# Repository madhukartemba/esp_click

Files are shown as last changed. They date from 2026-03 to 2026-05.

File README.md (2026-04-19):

# esp_click
This is a deep sleep ESP32 C6 push button device which transmits clicks via ESPNOW protocol. It uses an ESP32C6 microcontroller.

## Firmware build: broken RISC-V toolchain (PlatformIO)

ESP32-C6 uses the RISC-V toolchain (`riscv32-esp-elf-g++`). If the build fails with:

`sh: riscv32-esp-elf-g++: command not found` (exit 127)

the compiler package is missing, incomplete, or PlatformIO’s environment did not pick it up. From the firmware directory (`esp_click_firmware`), remove the toolchain and project build cache, then rebuild so PlatformIO re-downloads the toolchain:

```bash
cd esp_click_firmware
rm -rf .pio
rm -rf ~/.platformio/packages/toolchain-riscv32-esp
rm -rf ~/.platformio/tools/toolchain-riscv32-esp
pio run
```

Optional: remove all installed compiler packages (they reinstall on demand):

```bash
rm -rf ~/.platformio/packages/toolchain-*
```

Optional: prune unused PlatformIO packages:

```bash
pio system prune
```

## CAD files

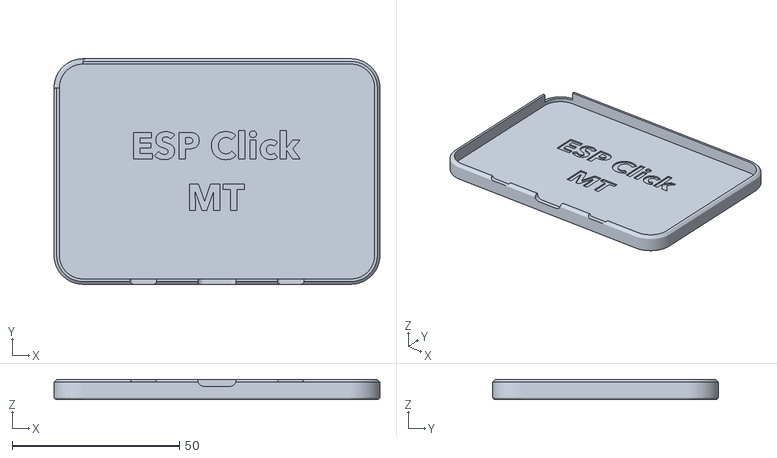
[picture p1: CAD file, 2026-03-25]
3D Print/Wall Mount 2.stl
97.4 x 67.4 x 6.00

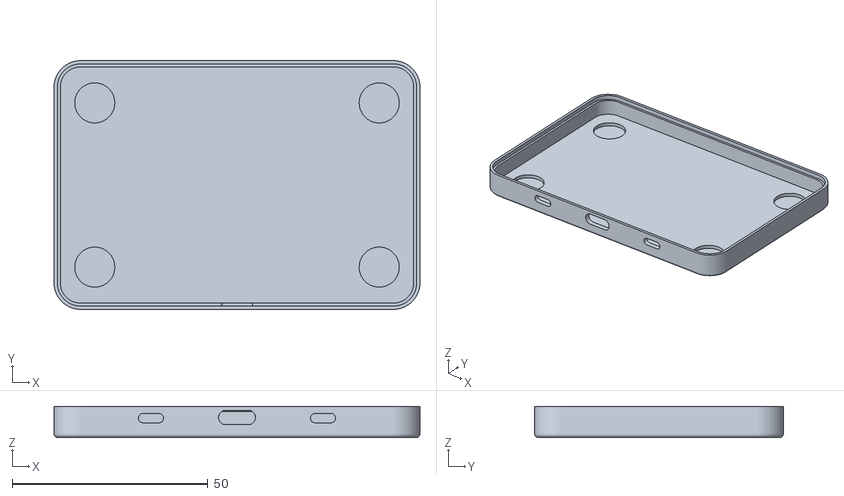
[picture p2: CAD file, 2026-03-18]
3D Print/Bottom.stl
93.6 x 63.6 x 8.00

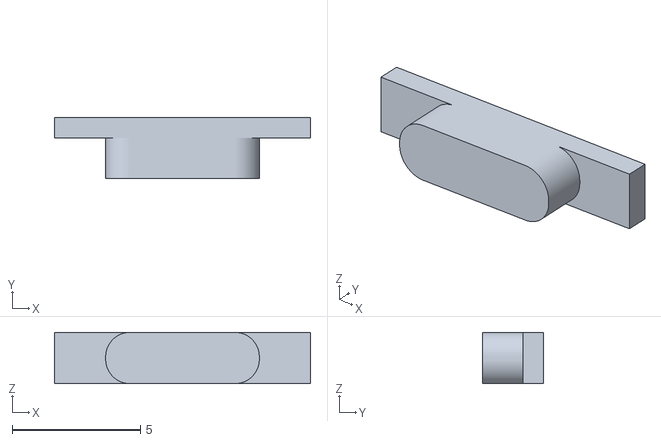
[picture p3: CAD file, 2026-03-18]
3D Print/CaseButton1.stl
10.0 x 2.40 x 2.00

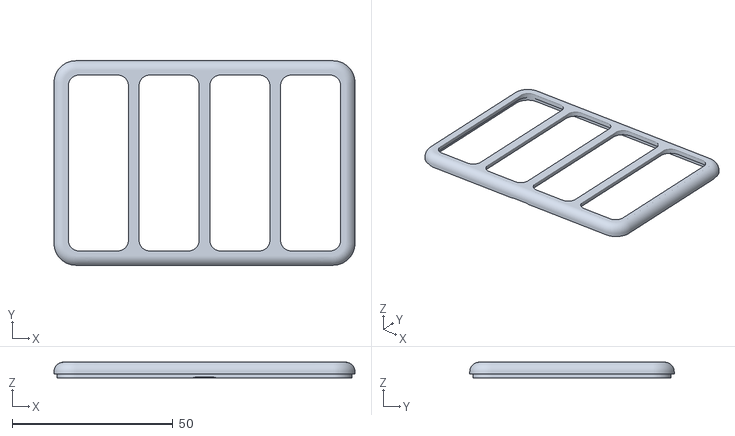
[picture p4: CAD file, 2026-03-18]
3D Print/Top.stl
93.6 x 63.6 x 4.90

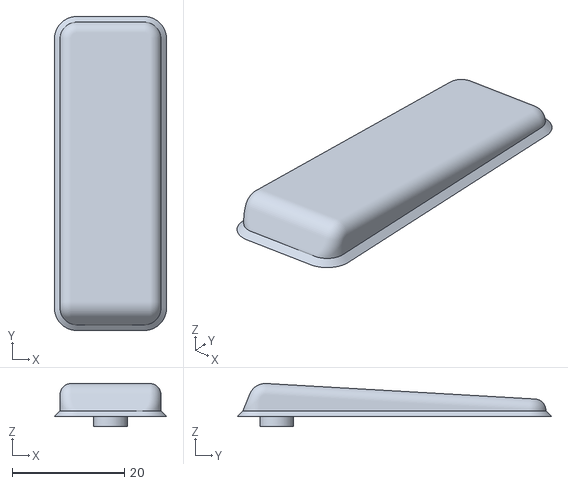
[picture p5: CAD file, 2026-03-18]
3D Print/Switch.stl
20.0 x 56.0 x 7.68

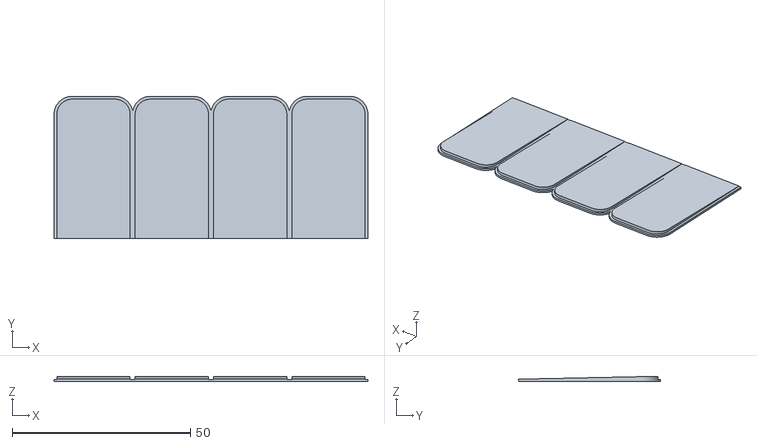
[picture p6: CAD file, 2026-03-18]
3D Print/SocketMount.stl
88.2 x 40.0 x 1.50

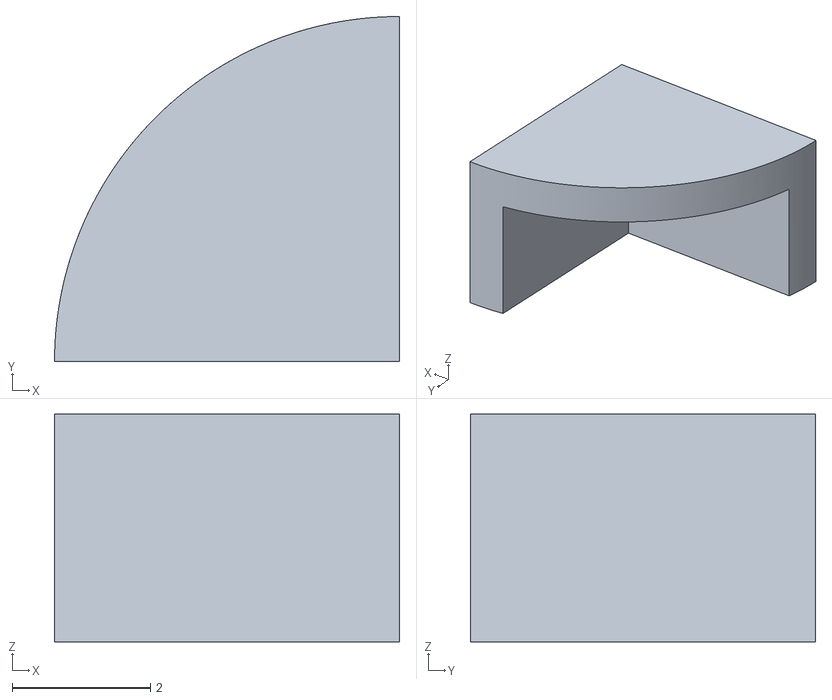
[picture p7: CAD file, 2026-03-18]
3D Print/LedGuide.stl
5.00 x 5.00 x 3.30

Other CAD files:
3D Print/ESPClick.f3z

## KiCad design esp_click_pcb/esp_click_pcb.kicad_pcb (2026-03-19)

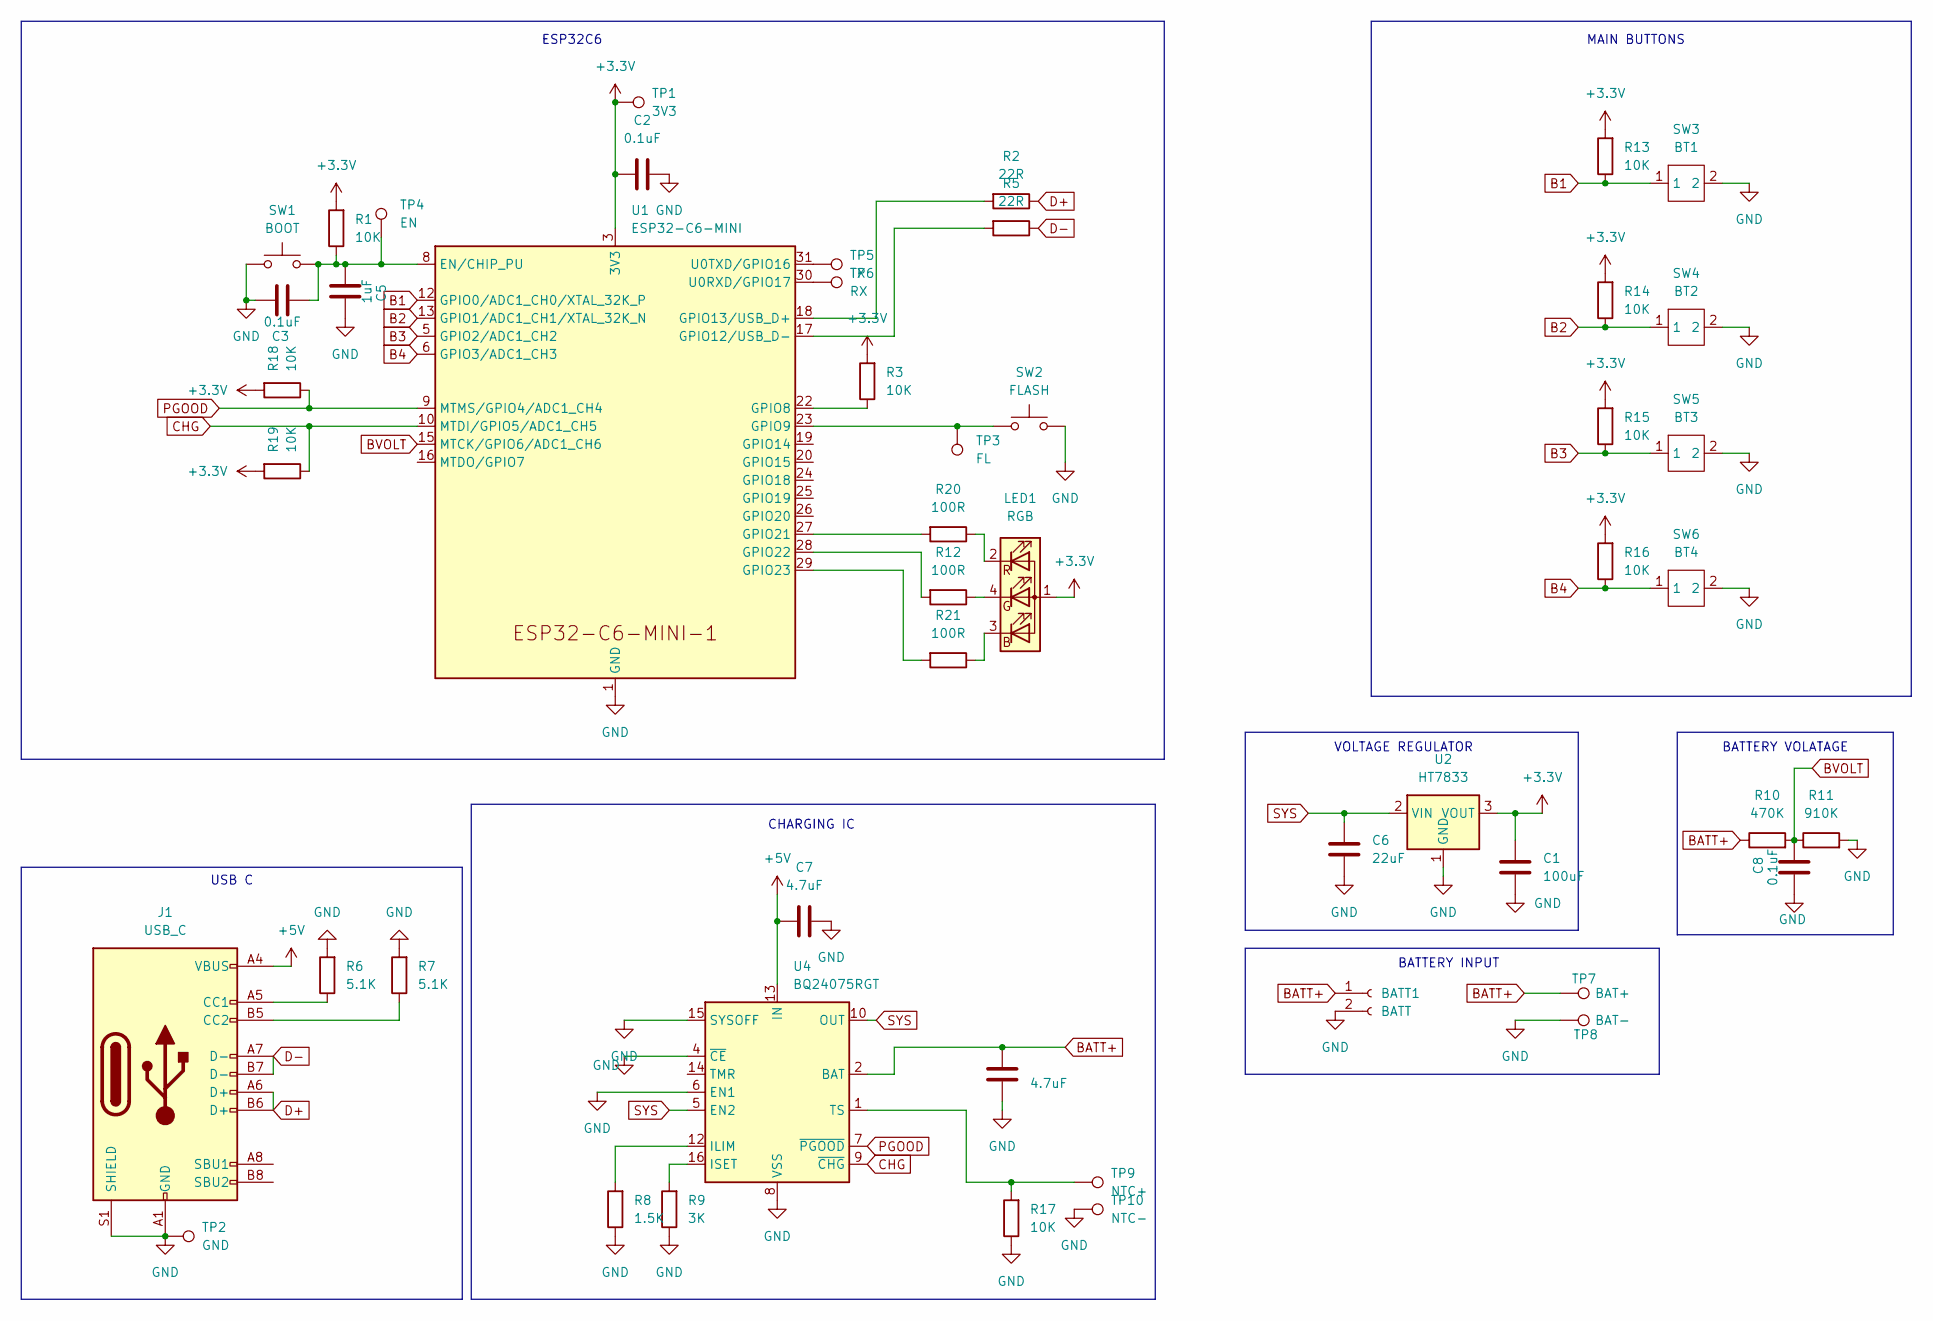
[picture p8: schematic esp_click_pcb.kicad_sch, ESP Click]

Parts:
BATT1: BATT; JST_SHL_SM02B-SHLS-TF_1x02-1MP_P1.00mm_Horizontal
C1: 100uF; C_0805_2012Metric
C2, C3, C8: 0.1uF; C_0603_1608Metric
C4, C7: 4.7uF; C_0805_2012Metric
C5: 1uF; C_0603_1608Metric
C6: 22uF; C_0805_2012Metric
J1: USB_C; USB_C_Receptacle_GCT_USB4110
LED1: RGB; XL-1615RGBC-RF
R1, R3, R13, R14, R15, R16, R17, R18, R19: 10K; R_0603_1608Metric
R2, R5: 22R; R_0603_1608Metric
R6, R7: 5.1K; R_0603_1608Metric
R8: 1.5K; R_0603_1608Metric
R9: 3K; R_0603_1608Metric
R10: 470K; R_0603_1608Metric
R11: 910K; R_0603_1608Metric
R12, R20, R21: 100R; R_0603_1608Metric
SW1: BOOT; TST-A002_0.6MM_BOSS
SW2: FLASH; TST-A002_0.6MM_BOSS
SW3: BT1; TS6643WS
SW4: BT2; TS6643WS
SW5: BT3; TS6643WS
SW6: BT4; TS6643WS
TP1: 3V3; TestPoint_Pad_D1.5mm
TP2: GND; TestPoint_Pad_D1.5mm
TP3: FL; TestPoint_Pad_D1.5mm
TP4: EN; TestPoint_Pad_D1.5mm
TP5: TX; TestPoint_Pad_D1.5mm
TP6: RX; TestPoint_Pad_D1.5mm
TP7: BAT+; TestPoint_Pad_D2.0mm
TP8: BAT-; TestPoint_Pad_D2.0mm
TP9: NTC+; TestPoint_Pad_D1.5mm
TP10: NTC-; TestPoint_Pad_D1.5mm
U1: ESP32-C6-MINI; ESP32-C6-MINI-1
U2: HT7833; SOT-89-3
U4: BQ24075RGT; VQFN-16-1EP_3x3mm_P0.5mm_EP1.6x1.6mm

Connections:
+3.3V: C1.1, C2.1, LED1.1 (A), R1.2, R3.2, R13.2, R14.2, R15.2, R16.2, R18.2, R19.2, TP1.1, U1.3 (3V3), U2.3 (VOUT)
+5V: C7.1, J1.A4 (VBUS), J1.A9 (VBUS), J1.B4 (VBUS), J1.B9 (VBUS), U4.13 (IN)
B1: R13.1, SW3.1, U1.12 (GPIO0/ADC1_CH0/XTAL_32K_P)
B2: R14.1, SW4.1, U1.13 (GPIO1/ADC1_CH1/XTAL_32K_N)
B3: R15.1, SW5.1, U1.5 (GPIO2/ADC1_CH2)
B4: R16.1, SW6.1, U1.6 (GPIO3/ADC1_CH3)
BATT+: BATT1.1, C4.1, R10.1, TP7.1, U4.2 (BAT), U4.3 (BAT)
BVOLT: C8.2, R10.2, R11.1, U1.15 (MTCK/GPIO6/ADC1_CH6)
CHG: R19.1, U1.10 (MTDI/GPIO5/ADC1_CH5), U4.9 (~CHG)
D+: J1.A6 (D+), J1.B6 (D+), R2.1
D-: J1.A7 (D-), J1.B7 (D-), R5.1
GND: BATT1.2, C1.2, C2.2, C3.2, C4.2, C5.2, C6.2, C7.2, C8.1, J1.A1 (GND), J1.A12 (GND), J1.B1 (GND), J1.B12 (GND), J1.S1 (SHIELD), R6.2, R7.2, R8.1, R9.1, R11.2, R17.1, SW1.1, SW2.2, SW3.2, SW4.2, SW5.2, SW6.2, TP2.1, TP8.1, TP10.1, U1.1 (GND), U1.2 (GND), U1.11 (GND), U1.14 (GND), U1.36 (GND), U1.37 (GND), U1.38 (GND), U1.39 (GND), U1.40 (GND), U1.41 (GND), U1.42 (GND), U1.43 (GND), U1.44 (GND), U1.45 (GND), U1.46 (GND), U1.47 (GND), U1.48 (GND), U1.49 (GND), U1.50 (GND), U1.51 (GND), U1.52 (GND), U1.53 (GND), U2.1 (GND), U4.4 (~CE), U4.6 (EN1), U4.8 (VSS), U4.15 (SYSOFF), U4.17 (VSS)
unnamed: J1.A5 (CC1), R6.1
unnamed: J1.B5 (CC2), R7.1
unnamed: LED1.3 (BK), R21.1
unnamed: LED1.4 (GK), R12.1
unnamed: LED1.2 (RK), R20.1
unnamed: C3.1, C5.1, R1.1, SW1.2, TP4.1, U1.8 (EN/CHIP_PU)
unnamed: R3.1, U1.22 (GPIO8)
unnamed: SW2.1, TP3.1, U1.23 (GPIO9)
unnamed: R5.2, U1.17 (GPIO12/USB_D-)
unnamed: R2.2, U1.18 (GPIO13/USB_D+)
unnamed: R20.2, U1.27 (GPIO21)
unnamed: R12.2, U1.28 (GPIO22)
unnamed: R21.2, U1.29 (GPIO23)
unnamed: TP6.1, U1.30 (U0RXD/GPIO17)
unnamed: TP5.1, U1.31 (U0TXD/GPIO16)
unnamed: R8.2, U4.12 (ILIM)
unnamed: R9.2, U4.16 (ISET)
unnamed: R17.2, TP9.1, U4.1 (TS)
PGOOD: R18.1, U1.9 (MTMS/GPIO4/ADC1_CH4), U4.7 (~PGOOD)
SYS: C6.1, U2.2 (VIN), U4.5 (EN2), U4.10 (OUT), U4.11 (OUT)

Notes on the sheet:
MAIN BUTTONS
CHARGING IC
BATTERY VOLATAGE
USB C
BATTERY INPUT
VOLTAGE REGULATOR
ESP32C6

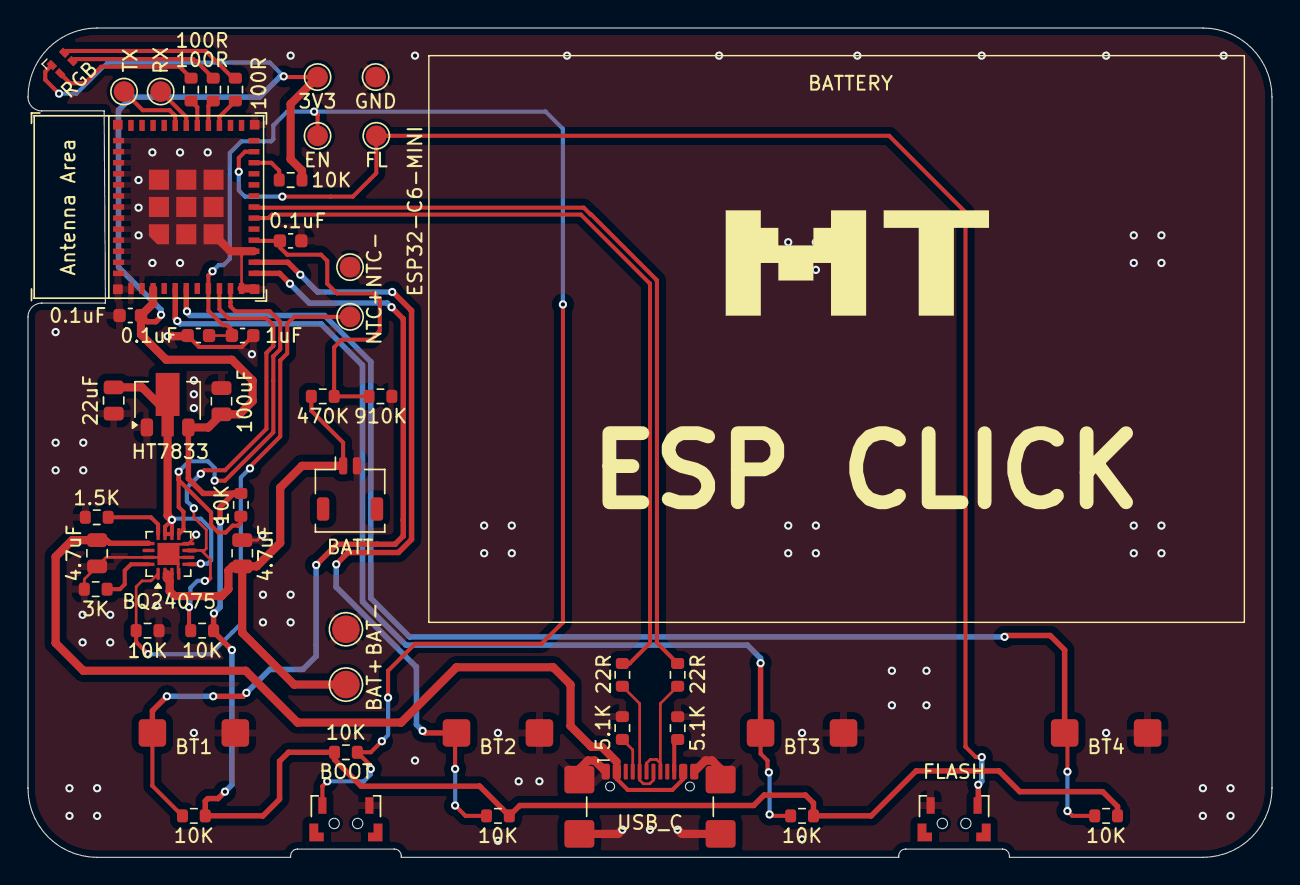
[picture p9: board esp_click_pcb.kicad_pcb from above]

Board: 2 copper layers, 90.0 x 60.0 mm, 50 parts (0 on the bottom side), 32 nets.

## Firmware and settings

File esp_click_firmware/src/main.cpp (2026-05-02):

#include "BoardConfig.h"
#include "AsyncLed.h"
#include "BatteryMonitor.h"
#include "Button.h"
#include "ButtonManager.h"
#include "SleepManager.h"
#include "EspNowController.h"

AsyncLed statusLed(
    BoardConfig::LED_PIN_R,
    BoardConfig::LED_PIN_G,
    BoardConfig::LED_PIN_B,
    COMMON_ANODE);

BatteryMonitor batteryMonitor(
    BoardConfig::BATTERY_PIN,
    BoardConfig::POWER_GOOD_PIN,
    BoardConfig::CHARGE_DETECT_PIN);

Button button1(BoardConfig::BTN1_PIN, INPUT, true);
Button button2(BoardConfig::BTN2_PIN, INPUT, true);
Button button3(BoardConfig::BTN3_PIN, INPUT, true);
Button button4(BoardConfig::BTN4_PIN, INPUT, true);
Button pairingButton(BoardConfig::PAIRING_MODE_PIN, INPUT_PULLUP, true);

ButtonManager buttonManager;

void setup()
{
  Serial.begin(9600);
  SleepManager::getInstance().begin();
  SleepManager::getInstance().setSleepTimeout(BoardConfig::SLEEP_TIMEOUT);

  buttonManager.registerButton(&button1);
  buttonManager.registerButton(&button2);
  buttonManager.registerButton(&button3);
  buttonManager.registerButton(&button4);
  buttonManager.registerButton(&pairingButton, false);

  buttonManager.registerMessageSink(&EspNowController::getInstance());

  buttonManager.begin();

  statusLed.begin();

  batteryMonitor.setVoltageDividerRatio(BoardConfig::VOLTAGE_DIVIDER_RATIO);

  batteryMonitor.onBatteryStatusChange(
      [](BatteryStatus oldStatus, BatteryStatus newStatus)
      {
        switch (newStatus)
        {
        case NOT_CONNECTED:
          Serial.println("NOT_CONNECTED");
          statusLed.set(LedMode::BLINK, 6, Color::RED);
          break;
        case CHARGING:
          Serial.println("CHARGING");
          statusLed.set(LedMode::PULSE, Color::RED, LedSpeed::GLACIAL);
          break;
        case DISCHARGING:
          Serial.println("DISCHARGING");
          if (oldStatus != DISCHARGING)
          {
            statusLed.set(LedMode::OFF);
          }
          break;
        case FULL_CHARGED:
          Serial.println("FULL_CHARGED");
          statusLed.set(LedMode::SOLID, Color::GREEN);
          break;
        case CHARGE_FAULT:
          Serial.println("CHARGE_FAULT");
          statusLed.set(LedMode::BLINK, 3, Color::RED);
          break;
        default:
          Serial.println("UNKNOWN");
          break;
        }
      });

  statusLed.registerOnAnimEnd(
      [](LedCommand cmd)
      {
        if (batteryMonitor.getBatteryStatus() == BatteryStatus::CHARGING)
        {
          statusLed.set(LedMode::PULSE, Color::RED, LedSpeed::GLACIAL);
        }
        else if (batteryMonitor.getBatteryStatus() == BatteryStatus::FULL_CHARGED)
        {
          statusLed.set(LedMode::SOLID, Color::GREEN);
        }
      });

  batteryMonitor.begin();

  EspNowController::getInstance().registerOnBeforeSend(
      [](Message message)
      {
        if (message.type == MessageType::BUTTON_PRESS)
        {
          if (batteryMonitor.getBatteryLevel() <= BoardConfig::LOW_BATTERY_THRESHOLD)
            statusLed.set(LedMode::SOLID, Color::RED);
          else if (message.data.buttonPress.event == SINGLE_PRESS)
            statusLed.set(LedMode::SOLID, Color::WHITE);
          else if (message.data.buttonPress.event == DOUBLE_PRESS)
            statusLed.set(LedMode::SOLID, Color::YELLOW);
          else if (message.data.buttonPress.event == LONG_PRESS)
            statusLed.set(LedMode::SOLID, Color::BLUE);
        }
      });

  EspNowController::getInstance().registerOnAfterSend(
      [](Message message, bool success)
      {
        if (message.type == MessageType::BUTTON_PRESS)
        {
          if (success)
          {
            statusLed.set(LedMode::OFF);
          }
          else
          {
            if (EspNowController::getInstance().isDevicePaired())
            {
              statusLed.set(LedMode::BLINK, 2, Color::RED);
            }
            else
            {
              statusLed.set(LedMode::BLINK, 5, Color::RED);
            }
          }
        }
      });

  EspNowController::getInstance().registerOnPairingInit(
      []()
      {
        statusLed.set(LedMode::PULSE, Color::MAGENTA);
      });

  EspNowController::getInstance().registerOnPairingComplete(
      [](bool success)
      {
        if (success)
        {
          statusLed.set(LedMode::BLINK, 3, Color::GREEN);
        }
        else
        {
          statusLed.set(LedMode::BLINK, 4, Color::RED);
        }
      });

  EspNowController::getInstance().registerOnUnpairComplete(
      [](bool success)
      {
        if (success)
        {
          statusLed.set(LedMode::BLINK, 3, Color::MAGENTA);
        }
        else
        {
          statusLed.set(LedMode::BLINK, 4, Color::MAGENTA);
        }
      });

  EspNowController::getInstance().begin(BoardConfig::PAIRING_MODE_PIN);
}

void loop() {}

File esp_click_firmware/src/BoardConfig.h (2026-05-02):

#pragma once
#include <Arduino.h>

namespace BoardConfig
{
    // LED Configuration
    constexpr uint8_t LED_PIN_R = 21;
    constexpr uint8_t LED_PIN_G = 22;
    constexpr uint8_t LED_PIN_B = 23;

    // Battery Monitor Configuration
    constexpr uint8_t BATTERY_PIN = 6;
    constexpr uint8_t POWER_GOOD_PIN = 4;
    constexpr uint8_t CHARGE_DETECT_PIN = 5;
    constexpr float VOLTAGE_DIVIDER_RATIO = 910.0f / 1380.0f;
    constexpr int LOW_BATTERY_THRESHOLD = 30;

    // Button Configuration
    constexpr uint8_t BTN1_PIN = 0;
    constexpr uint8_t BTN2_PIN = 1;
    constexpr uint8_t BTN3_PIN = 2;
    constexpr uint8_t BTN4_PIN = 3;

    // Pairing Mode Pin
    constexpr uint8_t PAIRING_MODE_PIN = 9; // GPIO9 is used to trigger pairing mode on boot when held LOW

    // Sleep Timeout
    constexpr unsigned long SLEEP_TIMEOUT = 1000; // 1 second

}

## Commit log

2026-03-05 half complete pcb design
    [esp_click_pcb.kicad_pcb, esp_click_pcb.kicad_sch]
2026-03-05 pcb layout complete
    [esp_click_pcb.kicad_pcb, esp_click_pcb.kicad_sch]
2026-03-06 layout finished pcb
    [esp_click_pcb.kicad_pcb]
2026-03-06 use rgb led directly
    [esp_click_pcb.kicad_pcb, esp_click_pcb.kicad_sch]
2026-03-06 complete pcb design
    [esp_click_pcb.kicad_pcb]
2026-03-06 production build
    [esp_click_pcb.kicad_pcb]
2026-03-13 update pcb design, rev2
    [esp_click_pcb.kicad_pcb, esp_click_pcb.kicad_sch]
2026-03-14 rev 3
    [esp_click_pcb.kicad_pcb, esp_click_pcb.kicad_sch]
2026-03-18 add 3d printing files
    [Bottom.stl, CaseButton1.stl, ESPClick.f3z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]
2026-03-18 add stl file
2026-03-19 update cap value
    [esp_click_pcb.kicad_pcb, esp_click_pcb.kicad_sch]
2026-03-19 add wall mount
    [ESPClick.f3z, Wall Mount.stl]
2026-03-20 initial led lib
2026-03-20 working button class gi
2026-03-20 init button manager
2026-03-21 working battery manager
2026-03-21 remove instant battery read
2026-03-21 register button pins
2026-03-23 sleep in led blink
2026-03-24 add battery logging
2026-03-24 fix led bug
2026-03-24 fix dreaded sleep bug
    [main.cpp]
2026-03-24 register wake up pin
2026-03-24 add led signals
2026-03-24 change led functions
2026-03-24 change led effect
2026-03-24 working voltage monitor
2026-03-24 add low battery thresh
2026-03-25 add wall mount 2
    [ESPClick.f3z, Wall Mount 2.stl, Wall Mount.stl]
2026-04-16 Revert "add zigbee"
    This reverts commit f91387ed248439d0d1b91da58089eec314216af4.
    [main.cpp]
2026-04-16 Revert "disable espnow for now"
    This reverts commit bdff6a1db95c68f1a96a91db538bf35517e9445f.
    [main.cpp]
2026-04-18 add pairing button
2026-04-19 skip register button as wakeup
    [main.cpp]
2026-04-20 start pairnig on button press if unpaired
2026-05-01 add 3d print files
